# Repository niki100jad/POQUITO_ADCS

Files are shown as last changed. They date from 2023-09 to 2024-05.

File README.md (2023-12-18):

# POQUITO_ADCS

An ADCS PCB for a PocketQube, designed for the [QUBIK platform](https://libre.space/projects/qubik/).

This project is based on the https://gitlab.com/librespacefoundation/pq9ish/pq9ish-comms-vu-hw
project by the Libre Space Foundation, which was used for the [QUBIK](https://libre.space/projects/qubik/)
PocketQube missions.

## Features

- 3 magnetorquer drivers
- 1 9-axis Inertial Measurement Unit
- Based on an STM32L476 MCU
- Compatible with the [PQ9 standard](https://dataverse.nl/dataset.xhtml?persistentId=doi:10.34894/6MVBCZ)

## Images

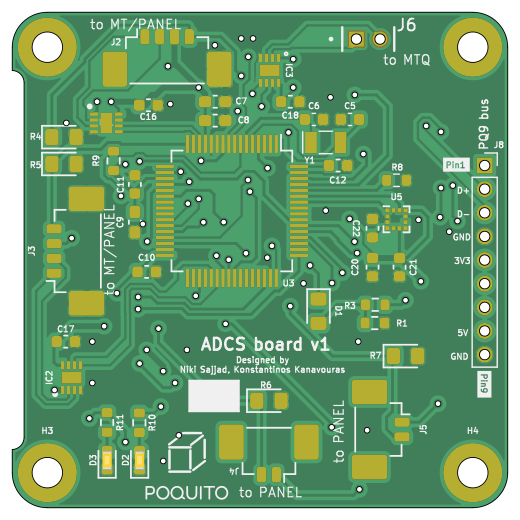
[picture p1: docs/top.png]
PCB top view


## Related Projects

- [POQUITO Panels](https://github.com/kongr45gpen/POQUITO-panels)

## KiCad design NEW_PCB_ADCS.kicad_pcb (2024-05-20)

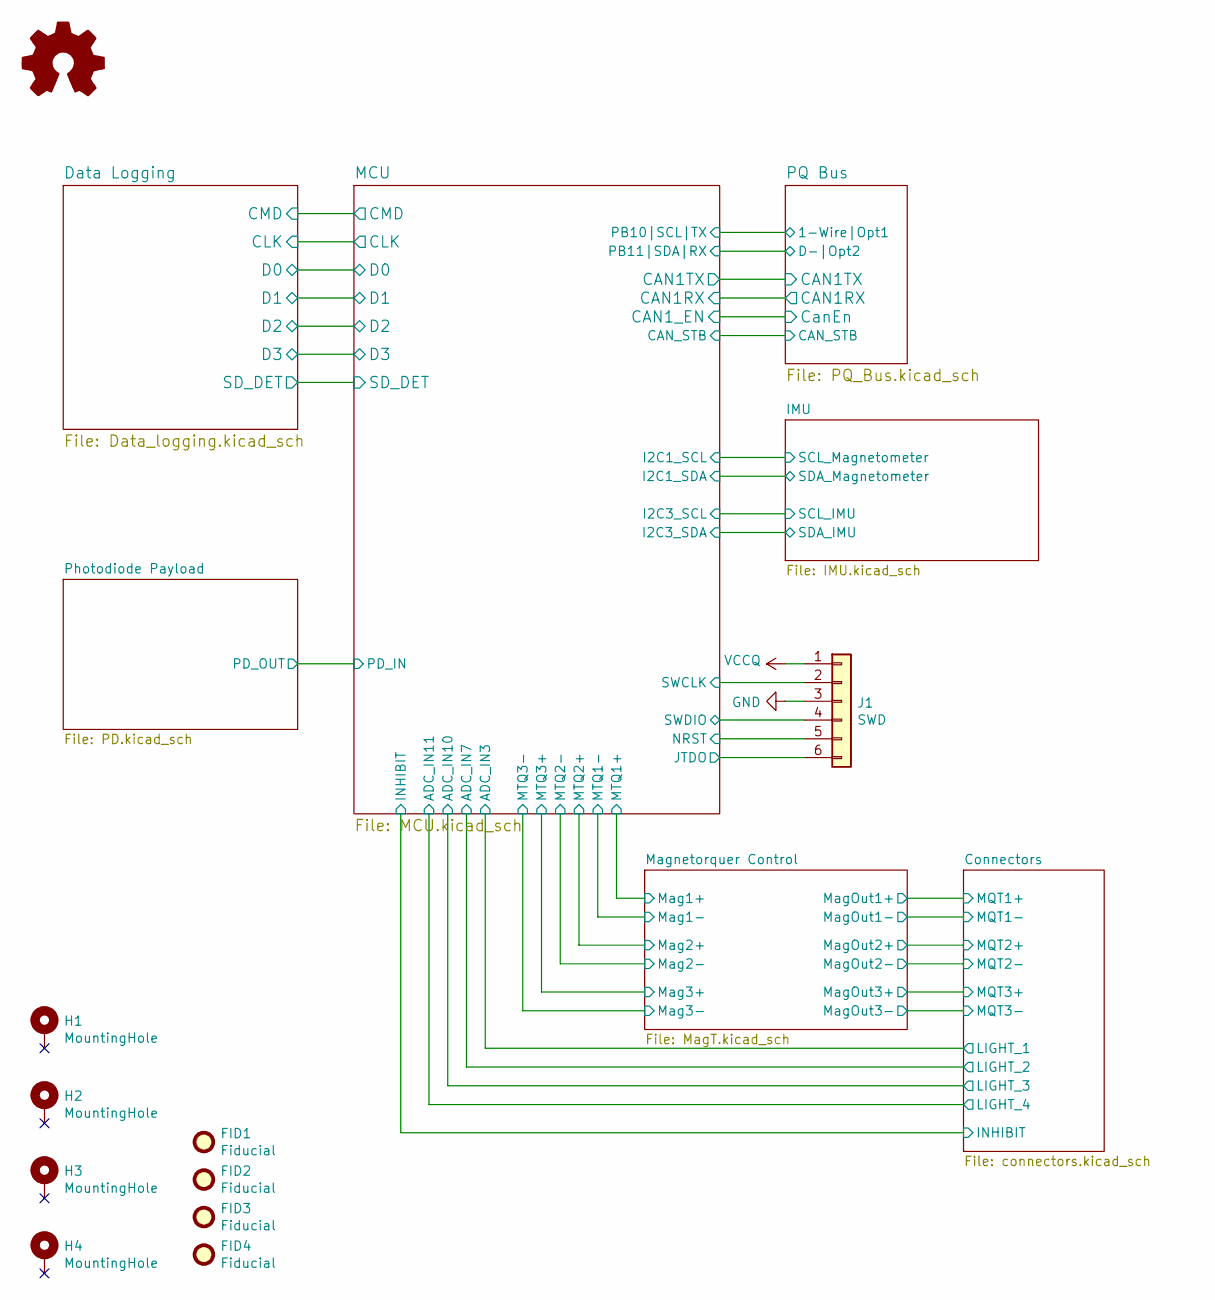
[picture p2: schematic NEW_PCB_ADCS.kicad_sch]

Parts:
FID1, FID2, FID3, FID4: Fiducial; Fiducial_0.5mm_Mask1.5mm
H1, H2, H3, H4: MountingHole; MountingHole_2.5mm_Pad
J1: SWD; Molex_PicoBlade_53261-0671_1x06-1MP_P1.25mm_Horizontal; Part Number 53261-0671

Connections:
/MCU/JTDO: J1.6; also elsewhere on the board
/MCU/NRST: J1.5; also elsewhere on the board
/MCU/SWCLK: J1.2; also elsewhere on the board
/MCU/SWDIO: J1.4; also elsewhere on the board
GND: J1.3; also elsewhere on the board
VCCQ: J1.1; also elsewhere on the board

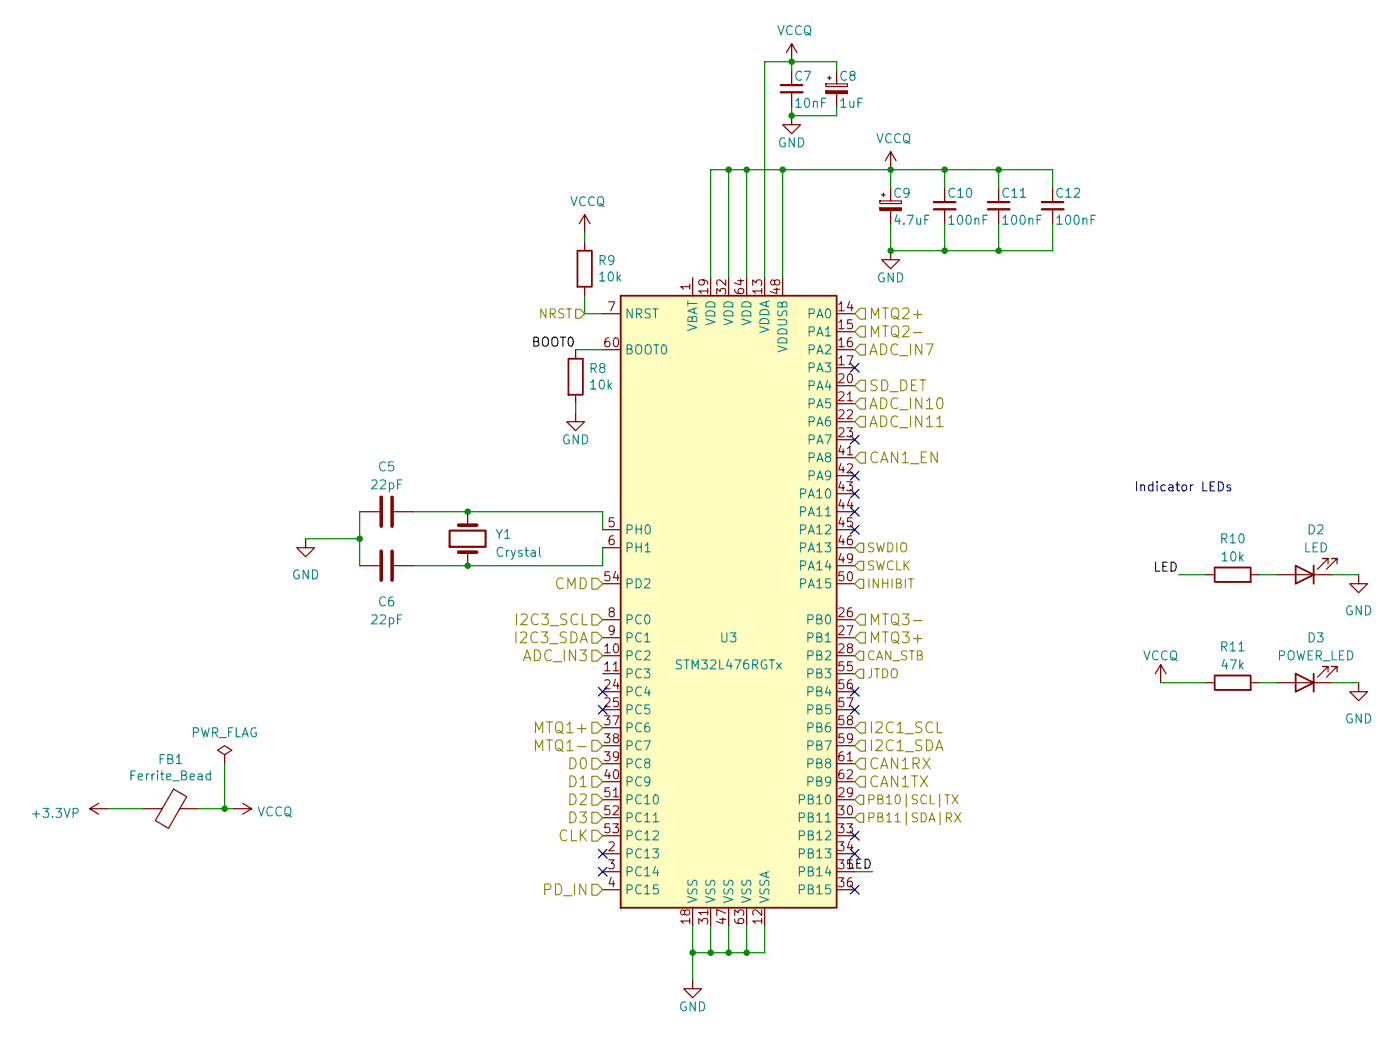
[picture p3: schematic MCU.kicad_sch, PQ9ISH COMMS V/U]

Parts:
C5, C6: 22pF; C_0603_1608Metric
C7: 10nF; C_0603_1608Metric_Pad1.08x0.95mm_HandSolder; Part Number C0603C103K9RACTU
C8: 1uF; C_0603_1608Metric_Pad1.08x0.95mm_HandSolder; Part Number CGB3B3X6S1A105K055AB
C9: 4.7uF; C_0603_1608Metric_Pad1.08x0.95mm_HandSolder; Part Number GRT188R60J475KE01D
C10, C11, C12: 100nF; C_0603_1608Metric; Part Number C0603C104K9RACTU
D2: LED; LED_0603_1608Metric; MPN LTST-C190KFKT
D3: POWER_LED; LED_0603_1608Metric; MPN LTST-C190KRKT
FB1: Ferrite_Bead; L_0603_1608Metric_Pad1.05x0.95mm_HandSolder; Part Number 742792664
R8, R9: 10k; R_0603_1608Metric; Part Number RE0603BRE0710KL
R10: 10k; R_0603_1608Metric; MPN RE0603BRE0710KL
R11: 47k; R_0603_1608Metric; Part Number RMCF0603FT47K0
U3: STM32L476RGTx; LQFP-64_10x10mm_P0.5mm; Part Number STM32L476RGT6
Y1: Crystal; Crystal_SMD_ECS_CSM3X-2Pin_7.6x4.1mm; MPN ECS-80-18-5PX-CKM-TR

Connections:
+3.3VP: FB1.2; also elsewhere on the board
/Connectors/INHIBIT: U3.50 (PA15); also elsewhere on the board
/Connectors/LIGHT_1: U3.10 (PC2); also elsewhere on the board
/Connectors/LIGHT_2: U3.16 (PA2); also elsewhere on the board
/Connectors/LIGHT_3: U3.21 (PA5); also elsewhere on the board
/Connectors/LIGHT_4: U3.22 (PA6); also elsewhere on the board
/Data Logging/CLK: U3.53 (PC12); also elsewhere on the board
/Data Logging/CMD: U3.54 (PD2); also elsewhere on the board
/Data Logging/D0: U3.39 (PC8); also elsewhere on the board
/Data Logging/D1: U3.40 (PC9); also elsewhere on the board
/Data Logging/D2: U3.51 (PC10); also elsewhere on the board
/Data Logging/D3: U3.52 (PC11); also elsewhere on the board
/Data Logging/SD_DET: U3.20 (PA4); also elsewhere on the board
/IMU/SCL_IMU: U3.8 (PC0); also elsewhere on the board
/IMU/SCL_Magnetometer: U3.58 (PB6); also elsewhere on the board
/IMU/SDA_IMU: U3.9 (PC1); also elsewhere on the board
/IMU/SDA_Magnetometer: U3.59 (PB7); also elsewhere on the board
/MCU/BOOT0: R8.1, U3.60 (BOOT0)
/MCU/CAN1RX: U3.61 (PB8); also elsewhere on the board
/MCU/CAN1TX: U3.62 (PB9); also elsewhere on the board
/MCU/CAN1_EN: U3.41 (PA8); also elsewhere on the board
/MCU/CAN_STB: U3.28 (PB2); also elsewhere on the board
/MCU/JTDO: U3.55 (PB3); also elsewhere on the board
/MCU/LED: R10.1, U3.35 (PB14)
/MCU/MTQ1+: U3.37 (PC6); also elsewhere on the board
/MCU/MTQ1-: U3.38 (PC7); also elsewhere on the board
/MCU/MTQ2+: U3.14 (PA0); also elsewhere on the board
/MCU/MTQ2-: U3.15 (PA1); also elsewhere on the board
/MCU/MTQ3+: U3.27 (PB1); also elsewhere on the board
/MCU/MTQ3-: U3.26 (PB0); also elsewhere on the board
/MCU/NRST: R9.2, U3.7 (NRST); also elsewhere on the board
/MCU/PB10|SCL|TX: U3.29 (PB10); also elsewhere on the board
/MCU/PB11|SDA|RX: U3.30 (PB11); also elsewhere on the board
/MCU/PD_IN: U3.4 (PC15); also elsewhere on the board
/MCU/SWCLK: U3.49 (PA14); also elsewhere on the board
/MCU/SWDIO: U3.46 (PA13); also elsewhere on the board
GND: C5.1, C6.1, C7.2, C8.2, C9.2, C10.2, C11.2, C12.2, D2.1 (K), D3.1 (K), R8.2, U3.12 (VSSA), U3.18 (VSS), U3.31 (VSS), U3.47 (VSS), U3.63 (VSS); also elsewhere on the board
unnamed: D2.2 (A), R10.2
unnamed: D3.2 (A), R11.2
unnamed: C5.2, U3.5 (PH0), Y1.2
unnamed: C6.2, U3.6 (PH1), Y1.1
VCCQ: C7.1, C8.1, C9.1, C10.1, C11.1, C12.1, FB1.1, R9.1, R11.1, U3.13 (VDDA), U3.19 (VDD), U3.32 (VDD), U3.48 (VDDUSB), U3.64 (VDD); also elsewhere on the board

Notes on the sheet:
Indicator LEDs

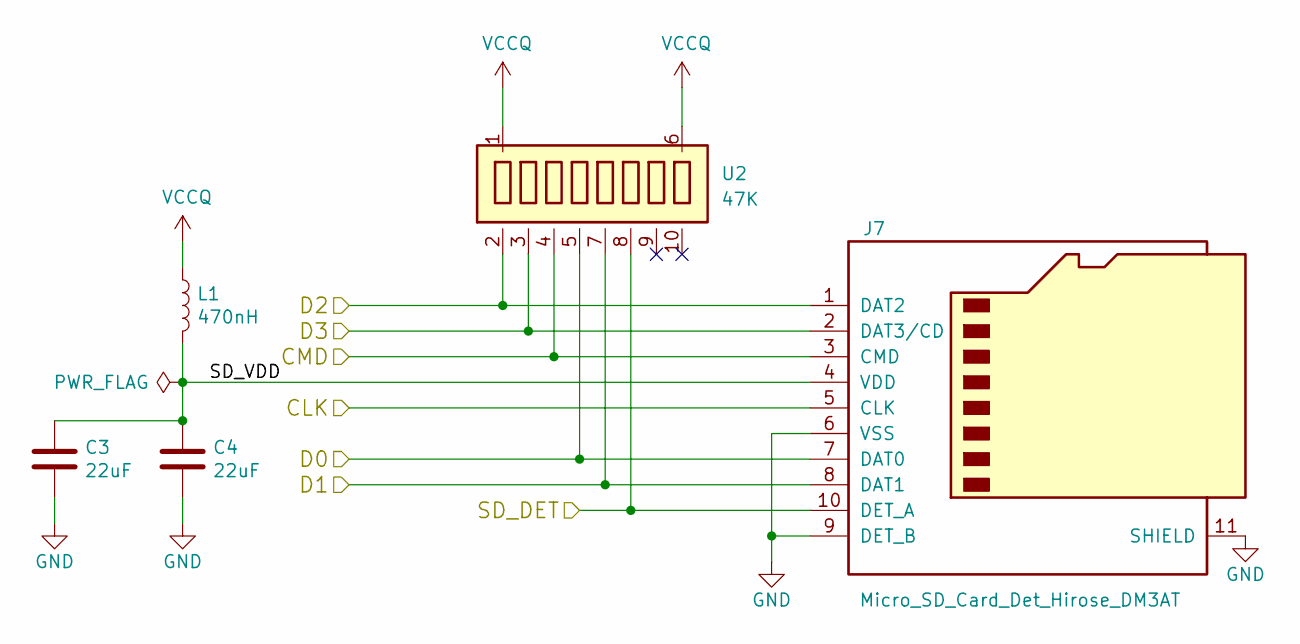
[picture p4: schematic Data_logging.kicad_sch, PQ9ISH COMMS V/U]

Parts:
C3, C4: 22uF; C_0603_1608Metric_Pad1.08x0.95mm_HandSolder; Part Number GRM188C80J226ME15D
J7: Micro_SD_Card_Det_Hirose_DM3AT; microSD_HC_Hirose_DM3D-SF; Part Number DM3D-SF
L1: 470nH; L_0603_1608Metric_Pad1.05x0.95mm_HandSolder; Part Number DFE18SANR47ME0L
U2: 47K; EXBD; Part Number EXBD10C473J

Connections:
/Data Logging/CLK: J7.5 (CLK); also elsewhere on the board
/Data Logging/CMD: J7.3 (CMD), U2.4 (R3); also elsewhere on the board
/Data Logging/D0: J7.7 (DAT0), U2.5 (R4); also elsewhere on the board
/Data Logging/D1: J7.8 (DAT1), U2.7 (R5); also elsewhere on the board
/Data Logging/D2: J7.1 (DAT2), U2.2 (R1); also elsewhere on the board
/Data Logging/D3: J7.2 (DAT3/CD), U2.3 (R2); also elsewhere on the board
/Data Logging/SD_DET: J7.10 (DET_A), U2.8 (R6); also elsewhere on the board
/Data Logging/SD_VDD: C3.1, C4.1, J7.4 (VDD), L1.2
GND: C3.2, C4.2, J7.6 (VSS), J7.9 (DET_B), J7.11 (SHIELD); also elsewhere on the board
VCCQ: L1.1, U2.1 (common), U2.6 (Common); also elsewhere on the board

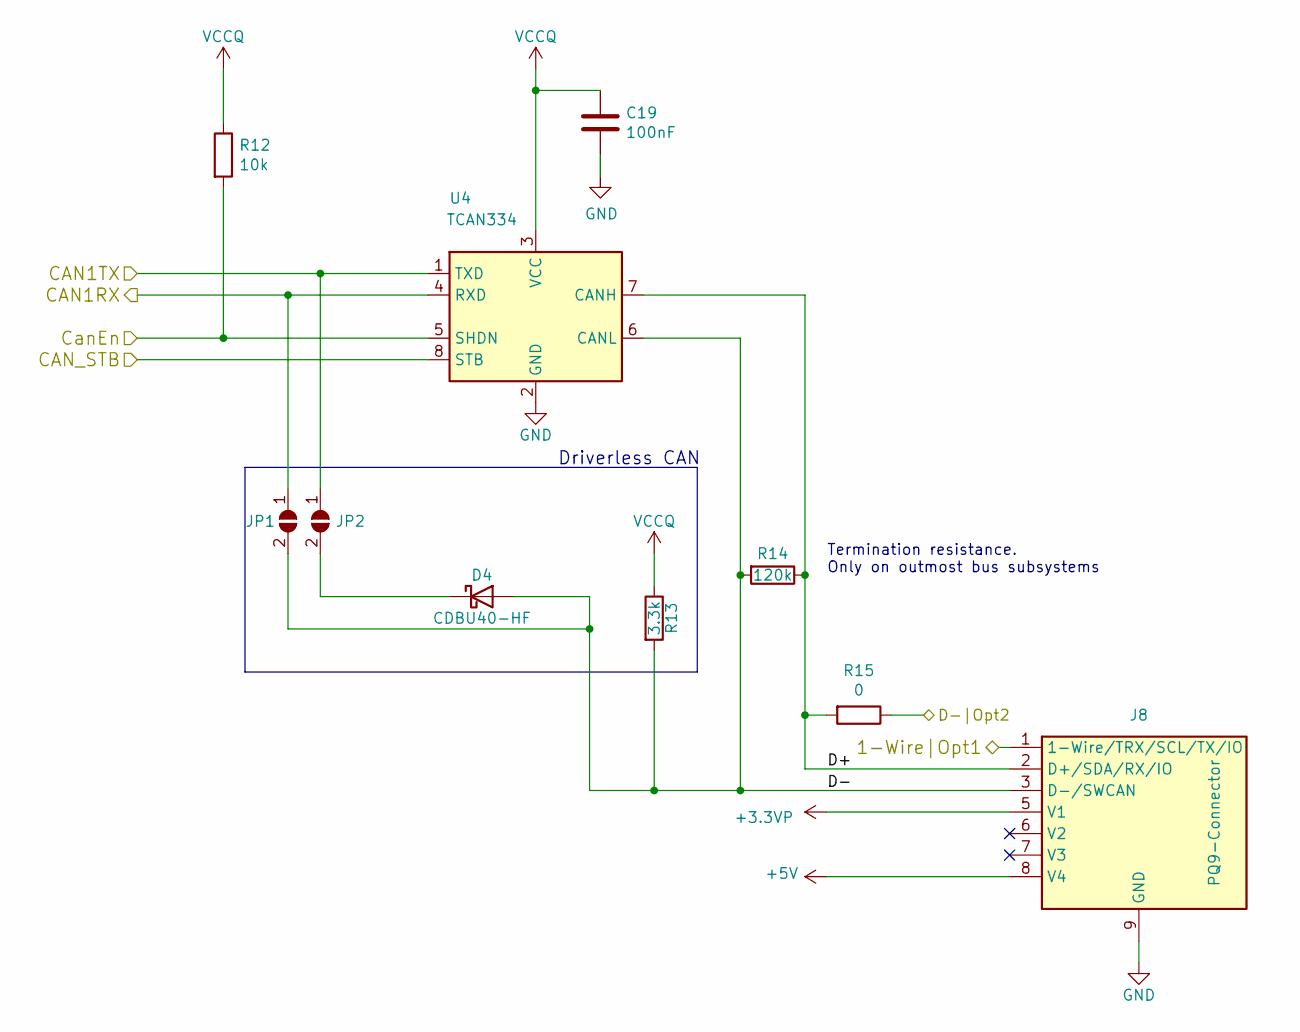
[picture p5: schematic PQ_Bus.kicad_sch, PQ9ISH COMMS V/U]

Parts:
C19: 100nF; C_0603_1608Metric; Part Number C0603C104K9RACTU
D4: CDBU40-HF; D_0603_1608Metric; Part Number CDBU40-HF
J8: PQ9-Connector; PinSocket_1x09_P2.00mm_Vertical; Part Number SQT-109-03-LS
JP1, JP2: SolderJumper_2_Open; SolderJumper-2_P1.3mm_Open_Pad1.0x1.5mm
R12: 10k; R_0603_1608Metric; Part Number RE0603BRE0710KL
R13: 3.3k; R_0603_1608Metric; Part Number MCT06030C3301FP500
R14: 120k; R_0603_1608Metric; Part Number CRCW0603120RFKEA
R15: 0; R_0603_1608Metric; Part Number RMCF0603ZT0R00
U4: TCAN334; SOT-23-8; Part Number TCAN334GDCNT

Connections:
+3.3VP: J8.5 (V1); also elsewhere on the board
+5V: J8.8 (V4)
/MCU/CAN1RX: JP1.1 (A), U4.4 (RXD); also elsewhere on the board
/MCU/CAN1TX: JP2.1 (A), U4.1 (TXD); also elsewhere on the board
/MCU/CAN1_EN: R12.2, U4.5 (SHDN); also elsewhere on the board
/MCU/CAN_STB: U4.8 (STB); also elsewhere on the board
/MCU/PB10|SCL|TX: J8.1 (1-Wire/TRX/SCL/TX/IO); also elsewhere on the board
/MCU/PB11|SDA|RX: R15.1; also elsewhere on the board
/PQ Bus/D+: J8.2 (D+/SDA/RX/IO), R14.1, R15.2, U4.7 (CANH)
/PQ Bus/D-: D4.2 (A), J8.3 (D-/SWCAN), JP1.2 (B), R13.2, R14.2, U4.6 (CANL)
GND: C19.2, J8.4 (GND), J8.9 (GND), U4.2 (GND); also elsewhere on the board
unnamed: D4.1 (K), JP2.2 (B)
VCCQ: C19.1, R12.1, R13.1, U4.3 (VCC); also elsewhere on the board

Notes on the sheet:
Driverless CAN
Termination resistance. Only on outmost bus subsystems

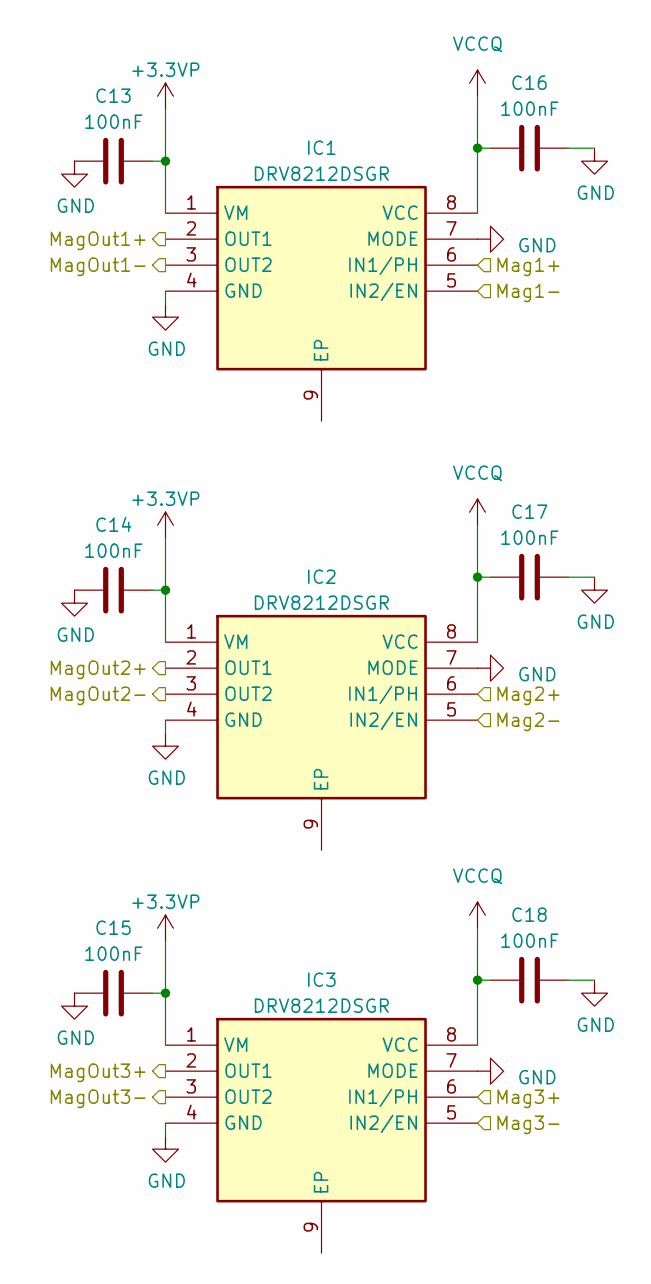
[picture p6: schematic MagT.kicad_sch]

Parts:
C13, C14, C15, C16, C17, C18: 100nF; C_0603_1608Metric; Part Number C0603C104K9RACTU
IC1, IC2, IC3: DRV8212DSGR; SON50P200X200X80-9N; Mouser Part Number 595-DRV8212DSGR

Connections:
+3.3VP: C13.2, C14.2, C15.2, IC1.1 (VM), IC2.1 (VM), IC3.1 (VM); also elsewhere on the board
/Connectors/MQT1+: IC1.2 (OUT1); also elsewhere on the board
/Connectors/MQT1-: IC1.3 (OUT2); also elsewhere on the board
/Connectors/MQT2+: IC2.2 (OUT1); also elsewhere on the board
/Connectors/MQT2-: IC2.3 (OUT2); also elsewhere on the board
/Connectors/MQT3+: IC3.2 (OUT1); also elsewhere on the board
/Connectors/MQT3-: IC3.3 (OUT2); also elsewhere on the board
/MCU/MTQ1+: IC1.6 (IN1/PH); also elsewhere on the board
/MCU/MTQ1-: IC1.5 (IN2/EN); also elsewhere on the board
/MCU/MTQ2+: IC2.6 (IN1/PH); also elsewhere on the board
/MCU/MTQ2-: IC2.5 (IN2/EN); also elsewhere on the board
/MCU/MTQ3+: IC3.6 (IN1/PH); also elsewhere on the board
/MCU/MTQ3-: IC3.5 (IN2/EN); also elsewhere on the board
GND: C13.1, C14.1, C15.1, C16.2, C17.2, C18.2, IC1.4 (GND), IC1.7 (MODE), IC1.9 (EP), IC2.4 (GND), IC2.7 (MODE), IC2.9 (EP), IC3.4 (GND), IC3.7 (MODE), IC3.9 (EP); also elsewhere on the board
VCCQ: C16.1, C17.1, C18.1, IC1.8 (VCC), IC2.8 (VCC), IC3.8 (VCC); also elsewhere on the board

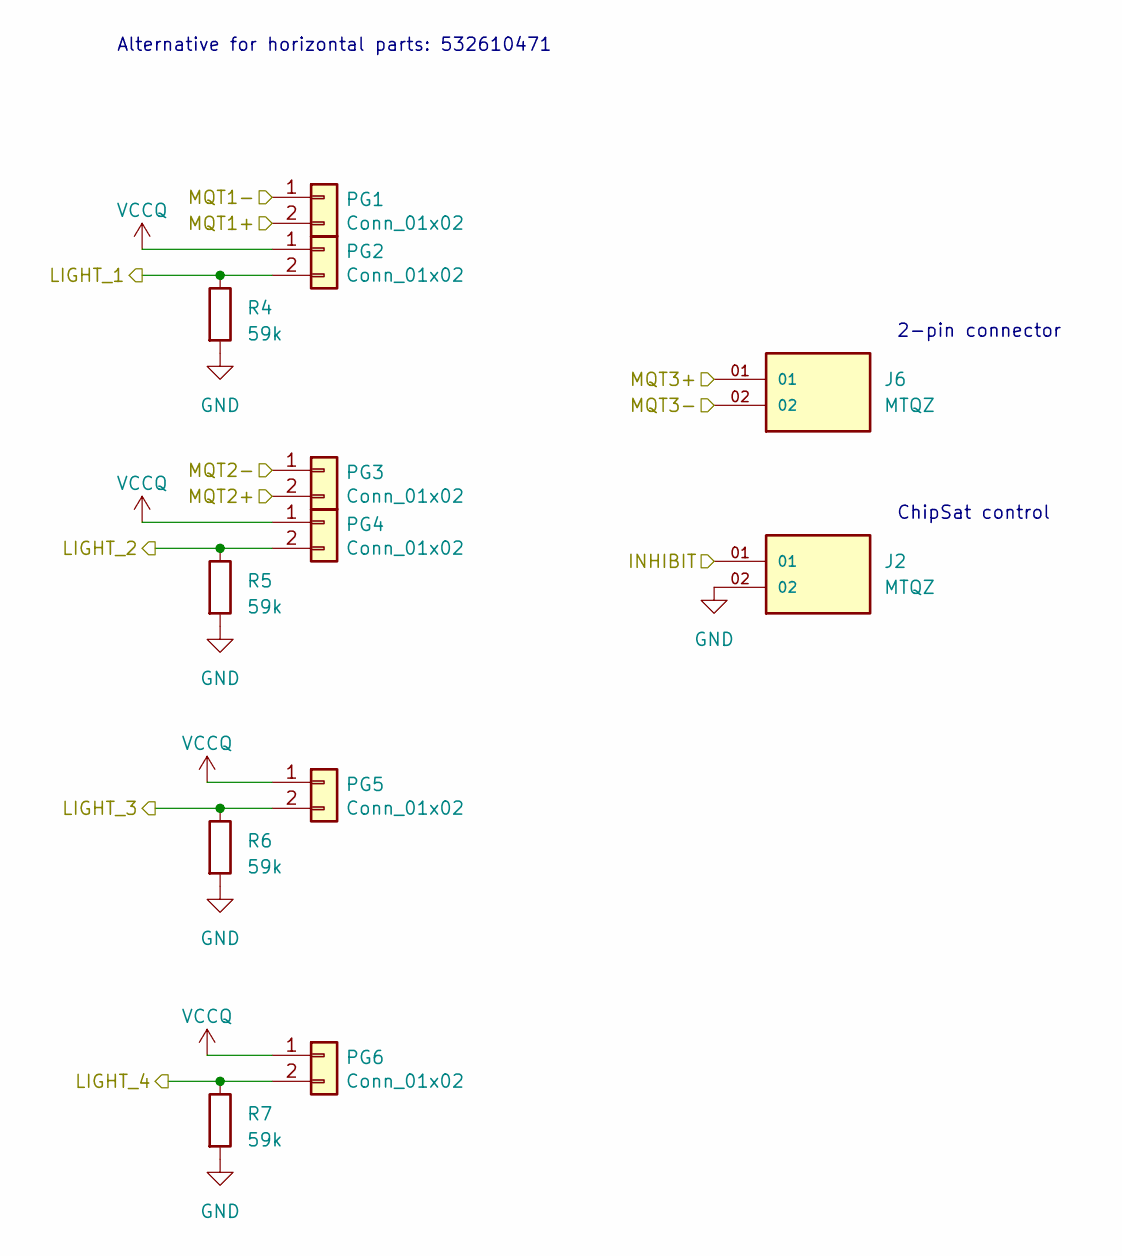
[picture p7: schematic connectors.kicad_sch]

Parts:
J2: MTQZ; JST_SH_SM02B-SRSS-TB_1x02-1MP_P1.00mm_Horizontal; Part Number SM02B-SRSS-TB
J6: MTQZ; SAMTEC_SQT-102-03-F-S; MPN SQT-102-03-F-S
PG1, PG2, PG3, PG4, PG5, PG6: Conn_01x02; MillMax_8290-22-002-20-001101_1x02_P2.54mm_Horizontal; Part Number 829-22-002-20-001101
R4, R5, R6, R7: 59k; LED_0805_2012Metric_Pad1.15x1.40mm_HandSolder; MPN ERA-6AEB5902V

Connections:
/Connectors/INHIBIT: J2.01; also elsewhere on the board
/Connectors/LIGHT_1: PG2.2, R4.1; also elsewhere on the board
/Connectors/LIGHT_2: PG4.2, R5.1; also elsewhere on the board
/Connectors/LIGHT_3: PG5.2, R6.1; also elsewhere on the board
/Connectors/LIGHT_4: PG6.2, R7.1; also elsewhere on the board
/Connectors/MQT1+: PG1.2; also elsewhere on the board
/Connectors/MQT1-: PG1.1; also elsewhere on the board
/Connectors/MQT2+: PG3.2; also elsewhere on the board
/Connectors/MQT2-: PG3.1; also elsewhere on the board
/Connectors/MQT3+: J6.01; also elsewhere on the board
/Connectors/MQT3-: J6.02; also elsewhere on the board
GND: J2.02, R4.2, R5.2, R6.2, R7.2; also elsewhere on the board
VCCQ: PG2.1, PG4.1, PG5.1, PG6.1; also elsewhere on the board

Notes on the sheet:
Alternative for horizontal parts: 532610471
ChipSat control
2-pin connector

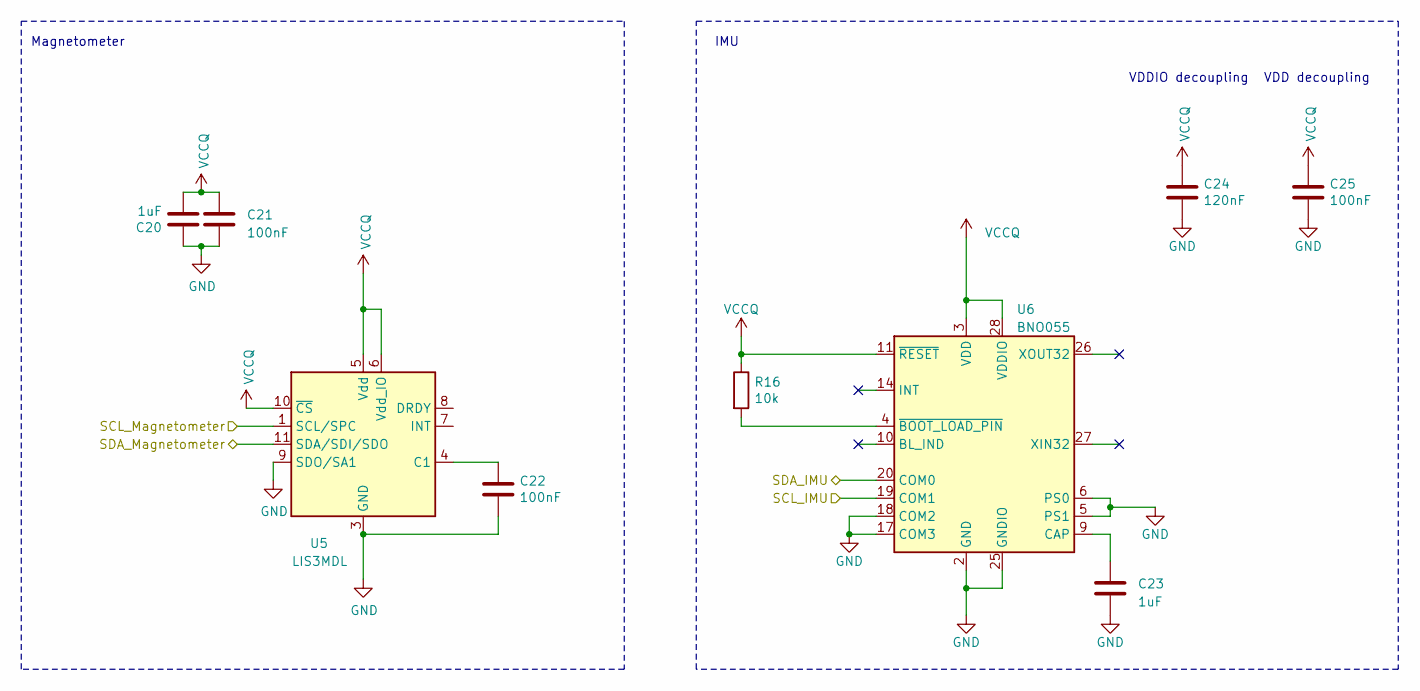
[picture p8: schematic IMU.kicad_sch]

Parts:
C20, C23: 1uF; C_0603_1608Metric; Part Number C0603C104K9RACTU
C21, C22, C25: 100nF; C_0603_1608Metric; Part Number C0603C104K9RACTU
C24: 120nF; C_0603_1608Metric; Part Number C0603C124J4RACTU
R16: 10k; R_0603_1608Metric; Part Number RE0603BRE0710KL
U5: LIS3MDL; LGA-12_2x2mm_P0.5mm; Part Number LIS3MDLTR
U6: BNO055; LGA-28_5.2x3.8mm_P0.5mm; Part Number BNO055

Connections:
/IMU/SCL_IMU: U6.19 (COM1); also elsewhere on the board
/IMU/SCL_Magnetometer: U5.1 (SCL/SPC); also elsewhere on the board
/IMU/SDA_IMU: U6.20 (COM0); also elsewhere on the board
/IMU/SDA_Magnetometer: U5.11 (SDA/SDI/SDO); also elsewhere on the board
GND: C20.1, C21.1, C22.2, C23.2, C24.2, C25.2, U5.2 (GND), U5.3 (GND), U5.9 (SDO/SA1), U5.12 (GND), U6.2 (GND), U6.5 (PS1), U6.6 (PS0), U6.15 (PIN15), U6.16 (PIN16), U6.17 (COM3), U6.18 (COM2), U6.25 (GNDIO); also elsewhere on the board
unnamed: C22.1, U5.4 (C1)
unnamed: C23.1, U6.9 (CAP)
unnamed: R16.2, U6.4 (~BOOT_LOAD_PIN)
VCCQ: C20.2, C21.2, C24.1, C25.1, R16.1, U5.5 (Vdd), U5.6 (Vdd_IO), U5.10 (~CS), U6.3 (VDD), U6.11 (~RESET), U6.28 (VDDIO); also elsewhere on the board

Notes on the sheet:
VDDIO decoupling
Magnetometer
IMU
VDD decoupling

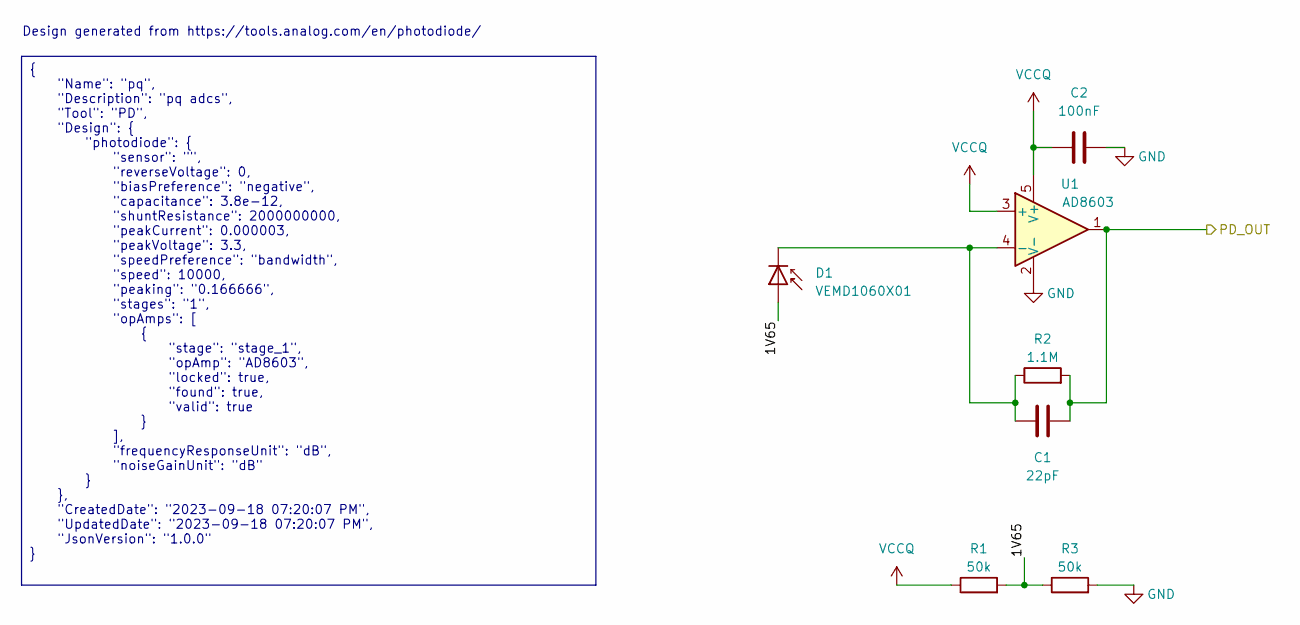
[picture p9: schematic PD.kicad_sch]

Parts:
C1: 22pF; C_0603_1608Metric
C2: 100nF; C_0603_1608Metric; Part Number C0603C104K9RACTU
D1: VEMD1060X01; LED_0805_2012Metric_Pad1.15x1.40mm_HandSolder; MPN VEMD1060X01
R1, R3: 50k; R_0603_1608Metric; Part Number RT0603BRD0750KL
R2: 1.1M; R_0603_1608Metric; Part Number AC0603FR-071M1L
U1: AD8603; TSOT-23-5; Part Number AD8603AUJZ-REEL

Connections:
/MCU/PD_IN: C1.1, R2.2, U1.1; also elsewhere on the board
/Photodiode Payload/1V65: D1.2 (A), R1.2, R3.1
GND: C2.2, R3.2, U1.2 (V-); also elsewhere on the board
unnamed: C1.2, D1.1 (K), R2.1, U1.4 (-)
VCCQ: C2.1, R1.1, U1.3 (+), U1.5 (V+); also elsewhere on the board

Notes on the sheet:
{ "Name": "pq", "Description": "pq adcs", "Tool": "PD", "Design": { "photodiode": { "sensor": "", "reverseVoltage": 0, "biasPreference": "negative", "capacitance": 3.8e-12, "shuntResistance": 2000000000, "peakCurrent": 0.000003, "peakVoltage": 3.3, "speedPreference": "bandwidth", "speed": 10000, "p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
Design generated from https://tools.analog.com/en/photodiode/

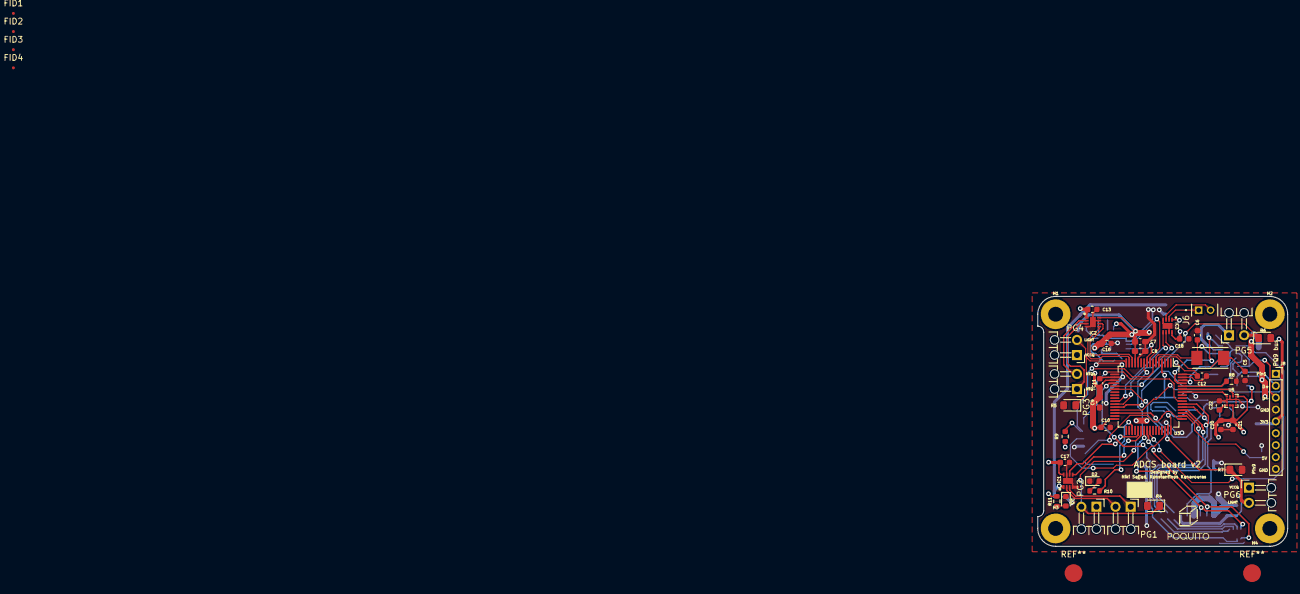
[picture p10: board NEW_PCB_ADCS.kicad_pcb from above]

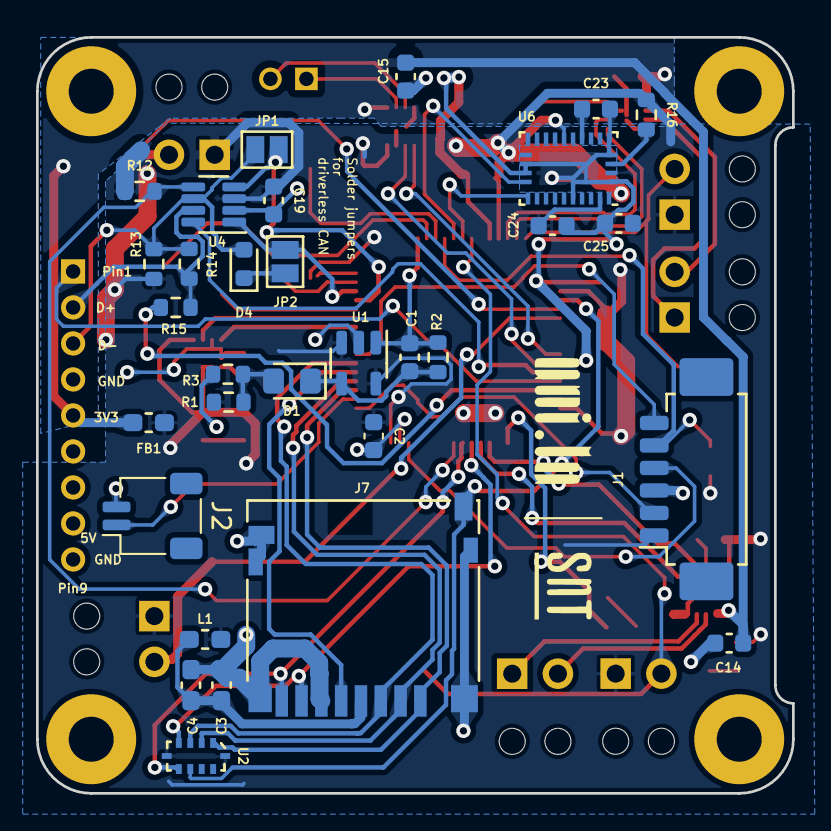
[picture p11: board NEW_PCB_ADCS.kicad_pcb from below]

Board: 2 copper layers, 42.0 x 42.0 mm, 78 parts (31 on the bottom side), 57 nets.

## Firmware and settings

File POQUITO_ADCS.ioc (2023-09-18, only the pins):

Mcu.UserName=STM32L476RGTx
PA0.Signal=S_TIM5_CH1
PA1.Signal=S_TIM5_CH2
PA4.Signal=GPIO_Input
PA6.Signal=S_TIM3_CH1
PA7.Signal=S_TIM3_CH2
PA8.GPIO_Label=CAN_DRV_EN
PA8.Signal=GPIO_Output
PB0.Signal=S_TIM3_CH3
PB1.Signal=S_TIM3_CH4
PB10.GPIO_Label=PQ_2
PB10.Signal=GPIO_Input
PB11.GPIO_Label=PQ_1
PB11.Signal=GPIO_Input
PB2.Signal=GPIO_Output
PB6.GPIO_Label=I2C_IMU_SCL
PB6.Signal=I2C1_SCL
PB7.GPIO_Label=I2C_IMU_SDA
PB7.Signal=I2C1_SDA
PB8.GPIO_Label=CAN1_RX
PB8.Signal=CAN1_RX
PB9.GPIO_Label=CAN1_TX
PB9.Signal=CAN1_TX
PC0.GPIO_Label=I2C_MAG_SCL
PC0.Signal=I2C3_SCL
PC1.GPIO_Label=I2C_MAG_SDA
PC1.Signal=I2C3_SDA
PC10.Signal=SDMMC1_D2
PC11.Signal=SDMMC1_D3
PC12.Signal=SDMMC1_CK
PC13.GPIO_Label=CAN STB
PC13.Signal=GPIO_Output
PC4.Signal=USART3_TX
PC5.GPIO_Label=IRDA_RX
PC5.Signal=USART3_RX
PC8.Signal=SDMMC1_D0
PC9.Signal=SDMMC1_D1
PD2.Signal=SDMMC1_CMD

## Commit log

2023-09-05 Remove useless files and add some git boilerplates
    [ADCS_PCB.kicad_sch]
2023-09-18 Magnetometer fixes\n\nCloses #2
    [IMU.kicad_sch, MagT.kicad_sch, mag.kicad_sch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]
2023-09-18 IMU schematic fixes
    Closes #3
    [IMU.kicad_sch]
2023-09-18 Clean-up schematic
    Closes #4
    [IMU.kicad_sch, MCU.kicad_sch, NEW_PCB_ADCS.kicad_sch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]
2023-09-18 Add I2C multiplexer
    [IMU.kicad_sch, MagT.kicad_sch, Multiplexer.kicad_sch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]
2023-09-18 Add connections between existing sheets
    [MCU.kicad_sch, Multiplexer.kicad_sch, NEW_PCB_ADCS.kicad_sch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]
2023-09-18 Add PD circuit
    [NEW_PCB_ADCS.kicad_sch, PD.kicad_sch, connectors.kicad_sch]
2023-09-18 Reannotate schematic
    [Data_logging.kicad_sch, IMU.kicad_sch, MCU.kicad_sch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]
2023-10-13 Create PCB layout and routing
    [IMU.kicad_sch, MCU.kicad_sch, MagT.kicad_sch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]
2023-10-17 Cleanup a few things
    [NEW_PCB_ADCS.kicad_pcb]
2023-10-26 most unconnected items are connected
    [NEW_PCB_ADCS.kicad_pcb]
2023-11-03 fix mistake
    [NEW_PCB_ADCS.kicad_pcb]
2023-11-03 Fix some issues
    [Data_logging.kicad_sch, IMU.kicad_sch, MCU.kicad_sch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]
2023-11-03 Add silk screen
    [MCU.kicad_sch, NEW_PCB_ADCS.kicad_pcb]
2023-11-07 Remove paste from connectors, relink GND mounting pins
    [NEW_PCB_ADCS.kicad_pcb, connectors.kicad_sch]
2023-11-07 Oops...forgot to save
    [MagZ_PCB.kicad_pcb, NEW_PCB_ADCS.kicad_pcb]
2023-12-19 Use pogo pins; move diode to back
    [MCU.kicad_sch, MagT.kicad_sch, MagZ_PCB.kicad_pcb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]
2023-12-22 Flip misaligned pogo pins
    [MagZ_PCB.kicad_pcb, NEW_PCB_ADCS.kicad_pcb]
2023-12-28 Update wrong MPNs
    [MCU.kicad_sch, NEW_PCB_ADCS.kicad_pcb, NEW_PCB_ADCS.kicad_sch]
2023-12-28 Add ChipSat inhibit
    [MCU.kicad_sch, NEW_PCB_ADCS.kicad_pcb, NEW_PCB_ADCS.kicad_sch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]
2023-12-28 Add teardrops
    [NEW_PCB_ADCS.kicad_pcb]
2024-01-15 Update some part numbers
    [IMU.kicad_sch, MCU.kicad_sch, MagT.kicad_sch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]
2024-01-24 Add fiducials
    [NEW_PCB_ADCS.kicad_pcb]
2024-01-30 Fix PTH mounting holes for MTQ
    [MagZ_PCB.kicad_pcb]
2024-01-30 Add cutout for panel L
    [MagZ_PCB.kicad_pcb]
2024-01-31 Fix outline DRC
    [MagZ_PCB.kicad_pcb]
2024-05-15 Update project to kicad 8
    [Data_logging.kicad_sch, IMU.kicad_sch, MCU.kicad_sch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]
2024-05-20 Fix footprints, brought to you by Spyros
    [NEW_PCB_ADCS.kicad_pcb]

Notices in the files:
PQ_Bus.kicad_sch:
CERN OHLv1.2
